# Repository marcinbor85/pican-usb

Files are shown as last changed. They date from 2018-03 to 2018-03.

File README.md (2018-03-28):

# pican-usb
Open-Hardware CAN-USB interface with optoisolation

## Features
- linux SOCKETCAN driver compatible (slcan)
- CANBUS side optoisolation (ISO1050 based)
- powered by USB (build-in DC/DC converter)
- hardware CAN and USB fifo buffers (8-deep CAN and 256-deep USB)
- virtual serial port (FT245 based)
- switchable build-in CAN terminal-resistor (symmetrical)
- up to 1Mbit throughput (no serial port bottleneck)
- EMC and ESD protection (both CAN and USB side)

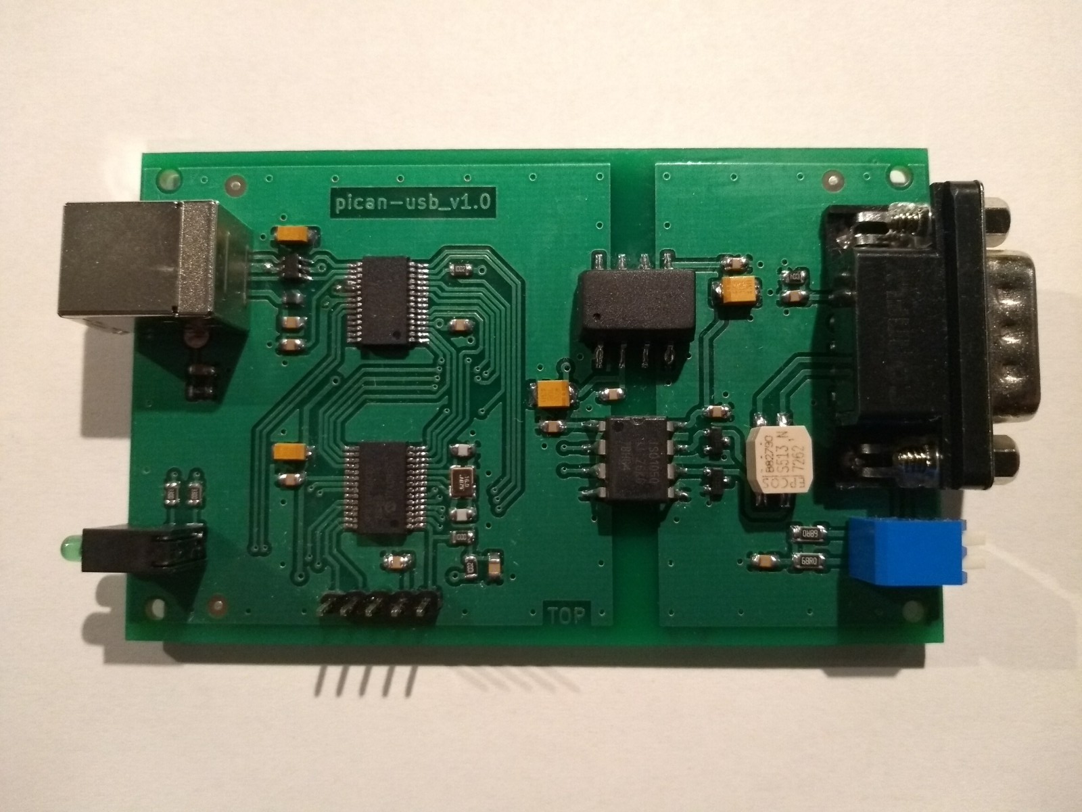
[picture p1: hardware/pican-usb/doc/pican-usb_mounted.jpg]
Board


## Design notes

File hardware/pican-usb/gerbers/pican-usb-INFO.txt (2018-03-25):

pican-usb_v1.0
--------------
laminat FR4 1.5mm 35um dwustronny
wymiary: 89.8mm x 55.3mm
metalizacja
soldermaska zielona
bez opisu elementów
cynowanie HAL
ilość otworów: 152
minimalny odstęp: 0.2mm
minimalna ścieżka: 0.4mm

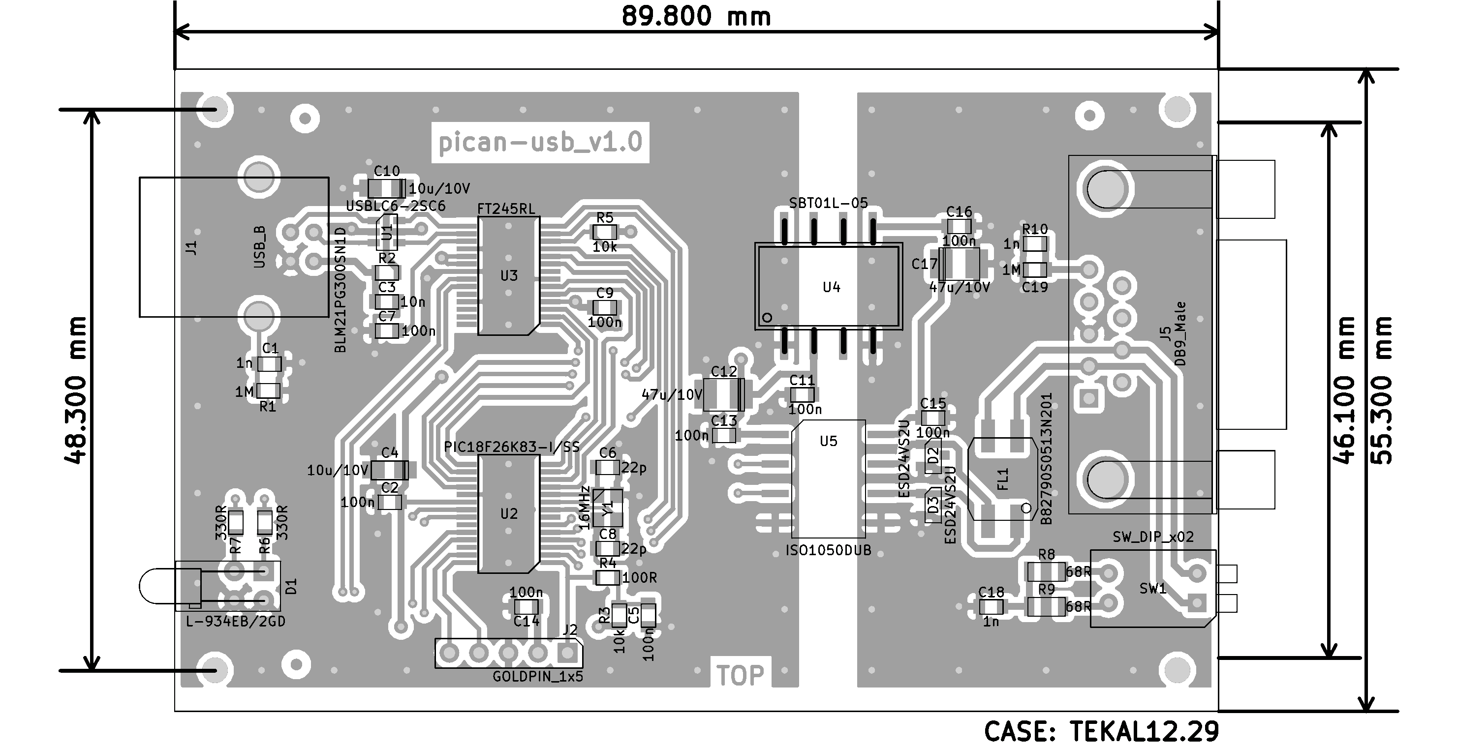
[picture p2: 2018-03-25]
hardware/pican-usb/doc/pican-usb.png

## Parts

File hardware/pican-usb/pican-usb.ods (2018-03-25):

Reference | Quantity | Identifier | Package | Value
U2 | 1 |  | Housings_SSOP:SSOP-28_5.3x10.2mm_Pitch0.65mm | PIC18F26K83-I/SS
J1 | 1 |  | mb_special:USB_B | USB_B
U3 | 1 |  | Housings_SSOP:SSOP-28_5.3x10.2mm_Pitch0.65mm | FT245RL
U5 | 1 |  | mb_special:ISO1050DUB | ISO1050DUB
FL1 | 1 |  | mb_special:B82790 | B82790S0513N201
R2 | 1 |  | Resistors_SMD:R_0805 | BLM21PG300SN1D
C6;C8 | 2 |  | Capacitors_SMD:C_0805 | 22p
C3 | 1 |  | Capacitors_SMD:C_0805 | 10n
C1;C18;C19 | 3 |  | Capacitors_SMD:C_0805 | 1n
R1;R10 | 2 |  | Resistors_SMD:R_0805 | 1M
R5;R3 | 2 |  | Resistors_SMD:R_0805 | 10k
D2;D3 | 2 |  | TO_SOT_Packages_SMD:SOT-23 | ESD24VS2U
C9;C13;C7;C2;C16;C15;C11;C14;C5 | 9 |  | Capacitors_SMD:C_0805 | 100n
C10;C4 | 2 |  | Capacitors_Tantalum_SMD:CP_Tantalum_Case-A_EIA-3216-18_Reflow | 10u/10V
U4 | 1 |  | mb_special:SBT01 | SBT01L-05
C17;C12 | 2 |  | Capacitors_Tantalum_SMD:CP_Tantalum_Case-B_EIA-3528-21_Reflow | 47u/10V
R4 | 1 |  | Resistors_SMD:R_0805 | 100R
D1 | 1 |  | mb_special:L-934EB2 | L-934EB/2GD
R6;R7 | 2 |  | Resistors_SMD:R_0805 | 330R
R8;R9 | 2 |  | Resistors_SMD:R_1206 | 68R
U1 | 1 |  | TO_SOT_Packages_SMD:SOT-23-6 | USBLC6-2SC6
J2 | 1 |  | Pin_Headers:Pin_Header_Straight_1x05_Pitch2.54mm | GOLDPIN_1x5
Y1 | 1 |  | Crystals:Crystal_SMD_3225-4pin_3.2x2.5mm | 16MHz
SW1 | 1 |  | Buttons_Switches_THT:SW_DIP_x2_W7.62mm_Piano | SW_DIP_x02
J5 | 1 |  | Connectors_DSub:DSUB-9_Male_Horizontal_Pitch2.77x2.84mm_EdgePinOffset7.70mm_Housed_MountingHolesOffset9.12mm | DB9_Male

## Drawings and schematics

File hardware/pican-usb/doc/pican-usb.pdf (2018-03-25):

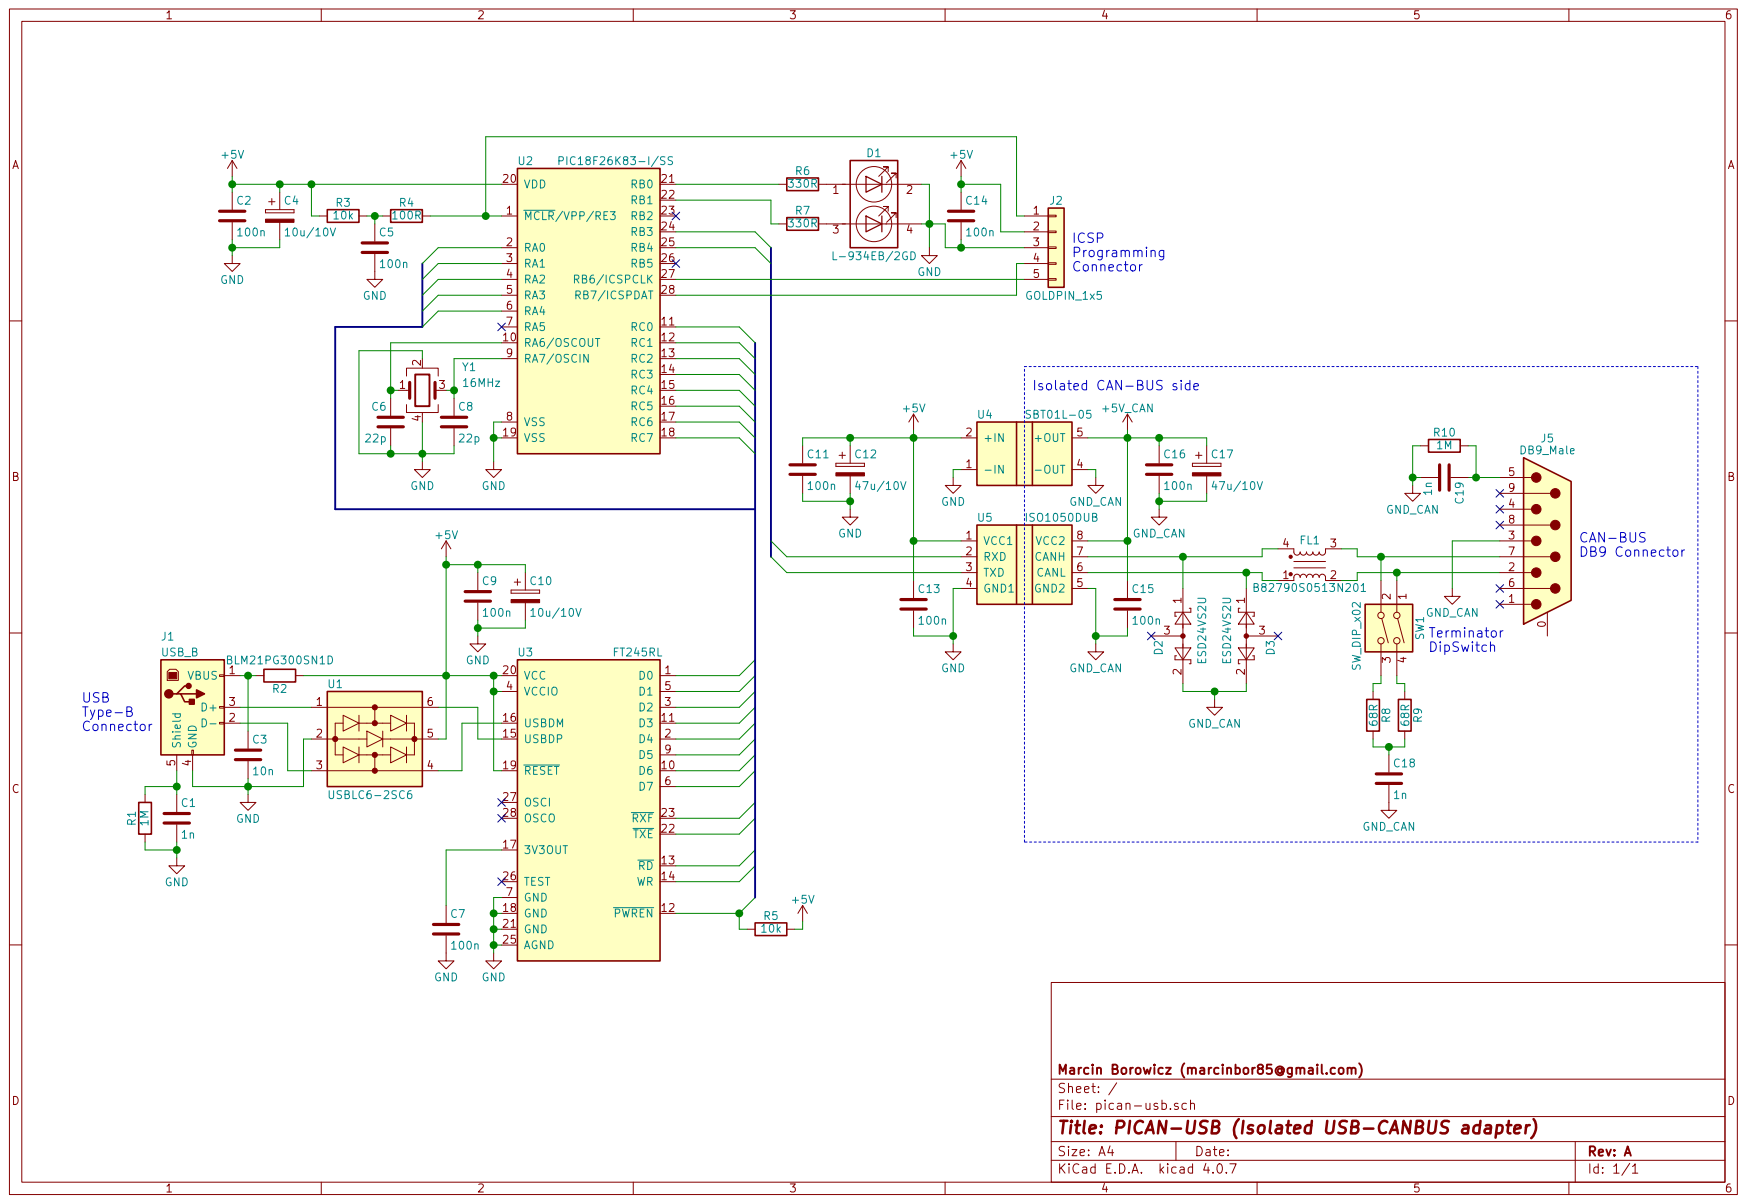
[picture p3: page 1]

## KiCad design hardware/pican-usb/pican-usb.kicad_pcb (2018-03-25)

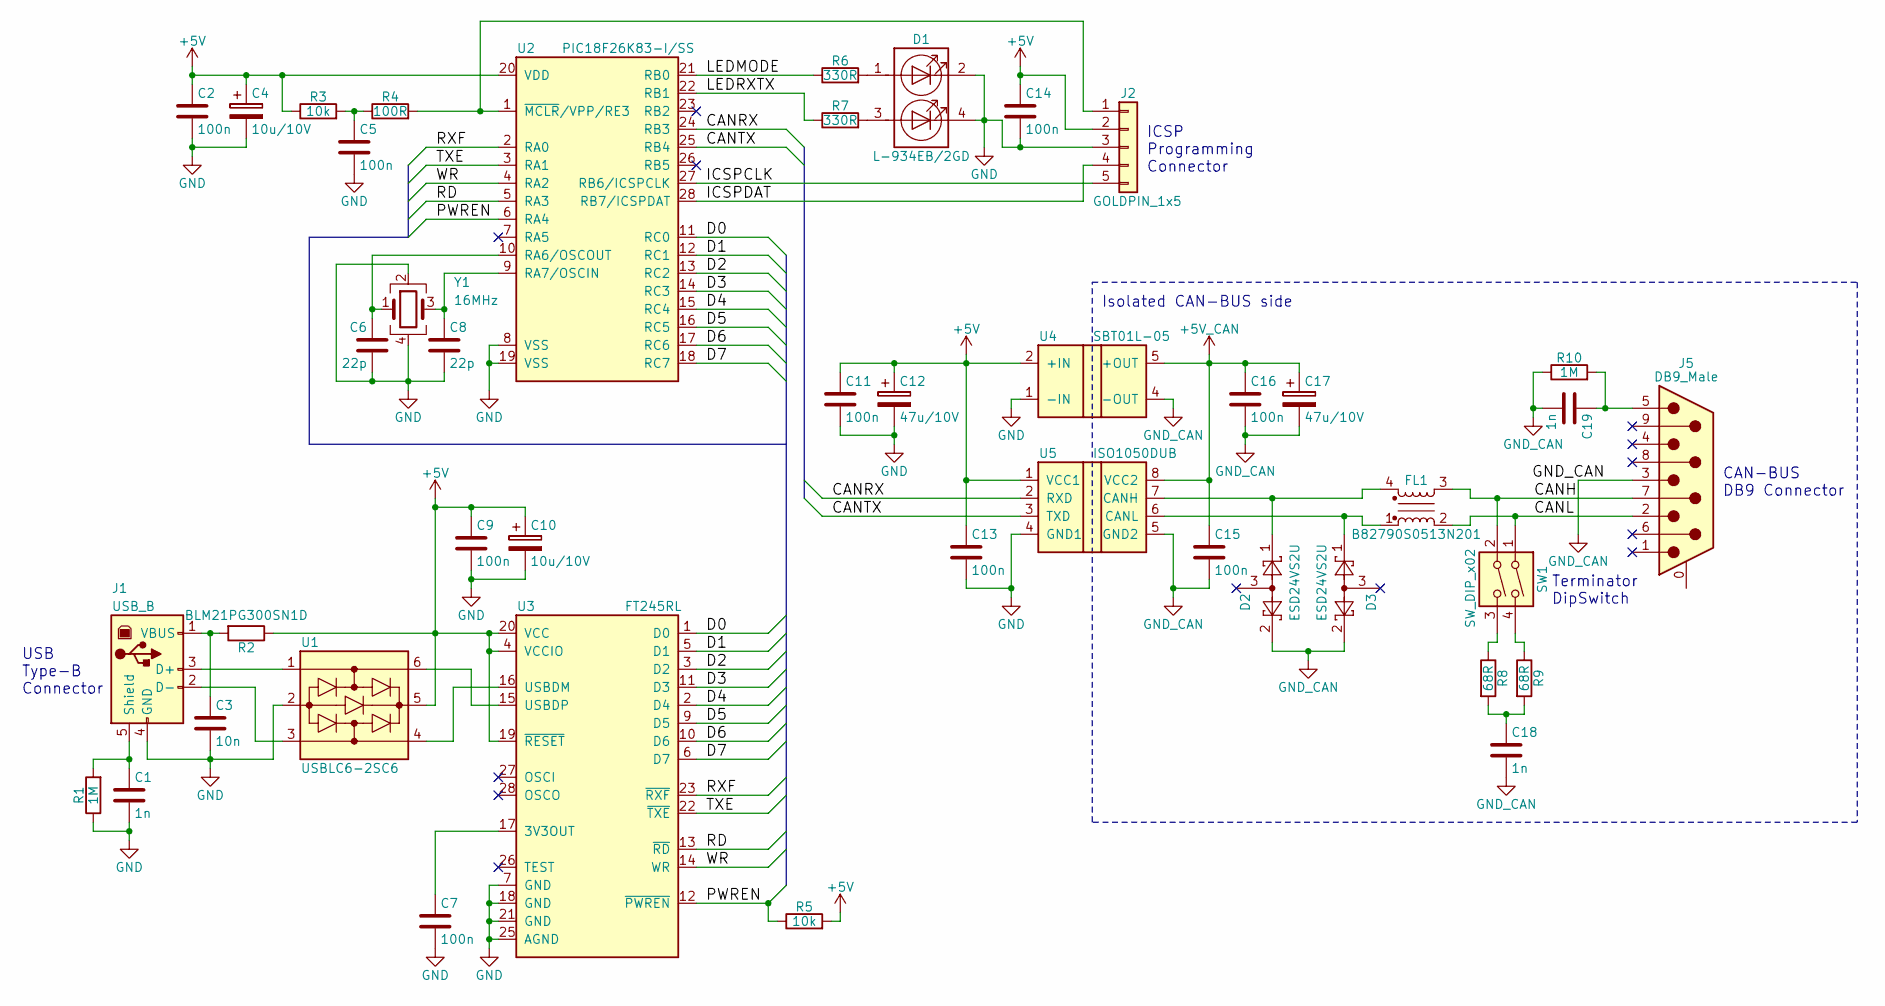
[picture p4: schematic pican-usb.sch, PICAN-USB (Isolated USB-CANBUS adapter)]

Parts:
C1, C18, C19: 1n; C_0805
C2, C5, C7, C9, C11, C13, C14, C15, C16: 100n; C_0805
C3: 10n; C_0805
C4, C10: 10u/10V; CP_Tantalum_Case-A_EIA-3216-18_Reflow
C6, C8: 22p; C_0805
C12, C17: 47u/10V; CP_Tantalum_Case-B_EIA-3528-21_Reflow
D1: L-934EB/2GD; L-934EB2
D2, D3: ESD24VS2U; SOT-23
FL1: B82790S0513N201; B82790
J1: USB_B
J2: GOLDPIN_1x5; Pin_Header_Straight_1x05_Pitch2.54mm
J5: DB9_Male; DSUB-9_Male_Horizontal_Pitch2.77x2.84mm_EdgePinOffset7.70mm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
R1, R10: 1M; R_0805
R2: BLM21PG300SN1D; R_0805
R3, R5: 10k; R_0805
R4: 100R; R_0805
R6, R7: 330R; R_0805
R8, R9: 68R; R_1206
SW1: SW_DIP_x02; SW_DIP_x2_W7.62mm_Piano
U1: USBLC6-2SC6; SOT-23-6
U2: PIC18F26K83-I/SS; SSOP-28_5.3x10.2mm_Pitch0.65mm
U3: FT245RL; SSOP-28_5.3x10.2mm_Pitch0.65mm
U4: SBT01L-05; SBT01
U5: ISO1050DUB
Y1: 16MHz; Crystal_SMD_3225-4pin_3.2x2.5mm

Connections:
+5V: C2.1, C4.1, C9.1, C10.1, C11.1, C12.1, C13.1, C14.1, J2.2, R2.1, R3.1, R5.2, U1.5, U2.20 (VDD), U3.4 (VCCIO), U3.19 (~RESET), U3.20 (VCC), U4.2 (+IN), U5.1 (VCC1)
+5V_CAN: C15.1, C16.1, C17.1, U4.5 (+OUT), U5.8 (VCC2)
/CANH: FL1.3, J5.7, SW1.2
/CANL: FL1.2, J5.2, SW1.1
/CANRX: U2.24 (RB3), U5.2 (RXD)
/CANTX: U2.25 (RB4), U5.3 (TXD)
/D0: U2.11 (RC0), U3.1 (D0)
/D1: U2.12 (RC1), U3.5 (D1)
/D2: U2.13 (RC2), U3.3 (D2)
/D3: U2.14 (RC3), U3.11 (D3)
/D4: U2.15 (RC4), U3.2 (D4)
/D5: U2.16 (RC5), U3.9 (D5)
/D6: U2.17 (RC6), U3.10 (D6)
/D7: U2.18 (RC7), U3.6 (D7)
/ICSPCLK: J2.5, U2.27 (RB6/ICSPCLK)
/ICSPDAT: J2.4, U2.28 (RB7/ICSPDAT)
/LEDMODE: R6.1, U2.21 (RB0)
/LEDRXTX: R7.1, U2.22 (RB1)
/PWREN: R5.1, U2.6 (RA4), U3.12 (~PWREN)
/RD: U2.5 (RA3), U3.13 (~RD)
/RXF: U2.2 (RA0), U3.23 (~RXF)
/TXE: U2.3 (RA1), U3.22 (~TXE)
/WR: U2.4 (RA2), U3.14 (WR)
GND: C1.2, C2.2, C3.2, C4.2, C5.2, C6.2, C7.2, C8.2, C9.2, C10.2, C11.2, C12.2, C13.2, C14.2, D1.2 (K1), D1.4 (K2), J1.4 (GND), J2.3, R1.1, U1.2, U2.8 (VSS), U2.19 (VSS), U3.7 (GND), U3.18 (GND), U3.21 (GND), U3.25 (AGND), U4.1 (-IN), U5.4 (GND1), Y1.2, Y1.4
GND_CAN: C15.2, C16.2, C17.2, C18.2, C19.2, D2.2, D3.2, J5.3, R10.1, U4.4 (-OUT), U5.5 (GND2)
unnamed: C1.1, J1.5 (Shield), R1.2
unnamed: C3.1, J1.1 (VBUS), R2.2
unnamed: C5.1, R3.2, R4.1
unnamed: C6.1, U2.10 (RA6/OSCOUT), Y1.1
unnamed: C7.1, U3.17 (3V3OUT)
unnamed: C8.1, U2.9 (RA7/OSCIN), Y1.3
unnamed: C18.1, R8.2, R9.2
unnamed: C19.1, J5.5, R10.2
unnamed: D1.1 (A1), R6.2
unnamed: D1.3 (A2), R7.2
unnamed: D2.1, FL1.4, U5.7 (CANH)
unnamed: D3.1, FL1.1, U5.6 (CANL)
unnamed: J1.2 (D-), U1.3
unnamed: J1.3 (D+), U1.1
unnamed: J2.1, R4.2, U2.1 (~MCLR~/VPP/RE3)
unnamed: R8.1, SW1.3
unnamed: R9.1, SW1.4
unnamed: U1.4, U3.16 (USBDM)
unnamed: U1.6, U3.15 (USBDP)

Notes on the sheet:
ICSP Programming Connector
CAN-BUS DB9 Connector
USB Type-B Connector
Terminator DipSwitch
Isolated CAN-BUS side

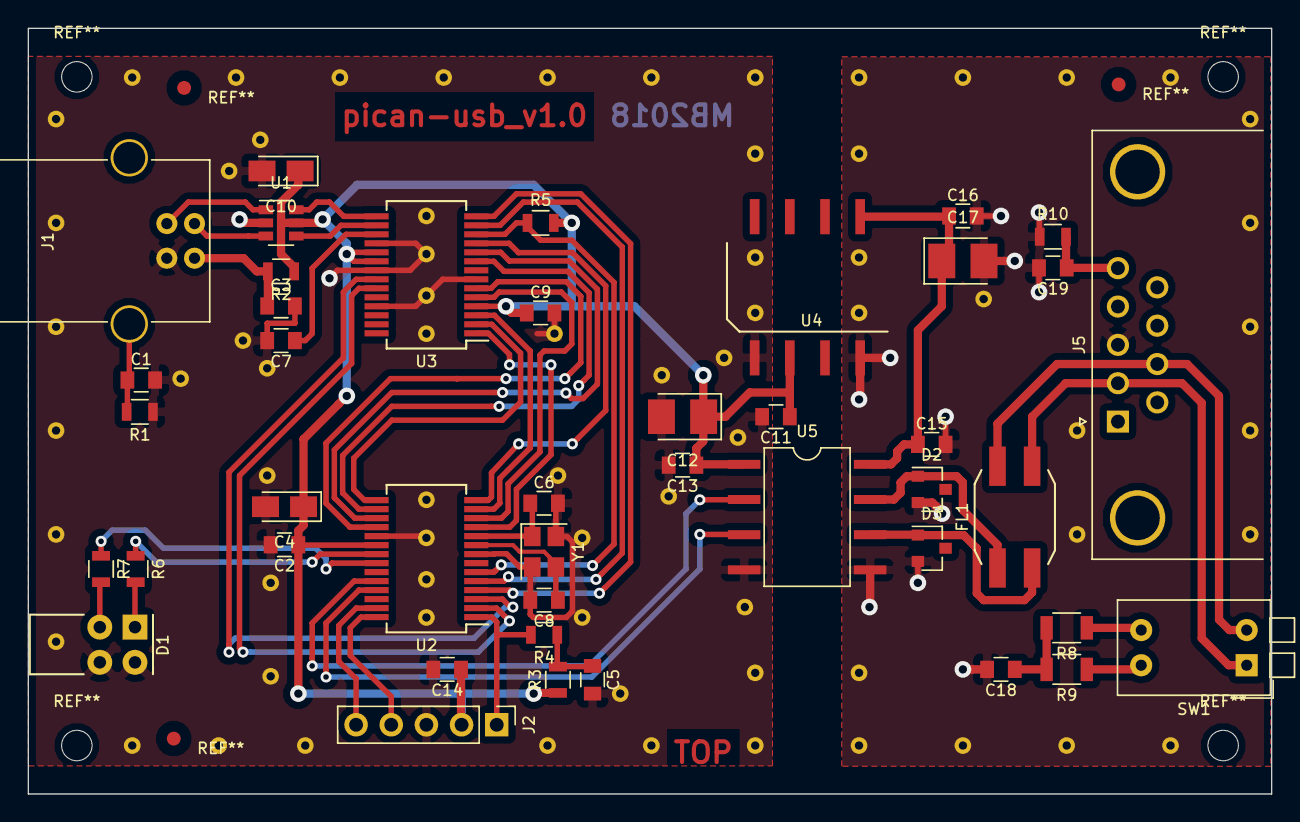
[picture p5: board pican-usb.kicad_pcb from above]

Board: 2 copper layers, 89.8 x 55.3 mm, 43 parts (0 on the bottom side), 44 nets.

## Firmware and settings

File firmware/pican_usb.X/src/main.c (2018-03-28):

#include "hw/hw.h"

#include <stdint.h>

#include "hal/tick.h"
#include "hal/leds.h"
#include "hal/can.h"

#include "hw/hw_ft245.h"

#include "net/ft245.h"
#include "net/slcan.h"

static uint8_t open_flag = 0;
static uint8_t std_ack_cntr = 0;
static uint8_t ext_ack_cntr = 0;
static uint8_t flash_flag = 0;
static uint8_t flash_state = 0;

static uint32_t last_tick = 0;
static uint32_t flash_tick = 0;

static struct slcan_object slcan;

static const uint8_t unique_serial[] = "FFFF";
static const uint8_t firmware_version[] = "0100";
static const uint8_t hardware_version[] = "0100";

static uint8_t recv_frame(struct can_frame *frame)
{
	if (open_flag == 0)
		return 1;
	if (can_send(frame) == 0)
		return 1;
	return 0;
}

static uint8_t open(uint32_t baudrate, uint8_t mode)
{
	if (open_flag != 0)
		return 1;
	
	switch (mode) {
	case SLCAN_MODE_NORMAL:
		can_init(baudrate, CAN_MODE_NORMAL);
		break;
	case SLCAN_MODE_LISTEN:
		can_init(baudrate, CAN_MODE_LISTEN);
		break;
	case SLCAN_MODE_LOOPBACK:
		can_init(baudrate, CAN_MODE_LOOPBACK);
		break;
	}
	open_flag = 1;
	return 0;
}

static uint8_t close(void)
{
	if (open_flag == 0)
		return 1;
	
	can_deinit();
	open_flag = 0;
	return 0;
}

static uint8_t get_status(void)
{
	return can_get_status();
}

static void send_byte(uint8_t b)
{
	while (ft245_put_byte(&ft245, b) == 0) {};
}

static struct slcan_interface slcan_iface = {
	recv_frame,
	open,
	close,
	get_status,
	send_byte,
	(uint8_t*)unique_serial,
	(uint8_t*)firmware_version,
	(uint8_t*)hardware_version
};

void can_send_callback(struct can_frame *frame)
{
	flash_flag = 1;
	slcan_tx_acknowledge(&slcan, frame);
}

static void clear_watchdog(void)
{
	CLRWDT();
}

static void leds_service(void)
{
	if (tick_get_value() - last_tick >= ((open_flag == 0) ? 500UL : 100UL)) {
		last_tick = tick_get_value();
		leds_toggle(LEDS_TYPE_OK);
	}

	switch (flash_state) {
	case 0:
		if (flash_flag == 1) {
			flash_flag = 0;
			flash_state = 1;
		}
		break;
	case 1:
		flash_tick = tick_get_value();
		leds_set(LEDS_TYPE_RXTX, 1);
		flash_state = 2;
		break;
	case 2:
		if (tick_get_value() - flash_tick >= 50UL) {
			flash_tick = tick_get_value();
			leds_set(LEDS_TYPE_RXTX, 0);
			flash_state = 3;
		}
		break;
	case 3:
		if (tick_get_value() - flash_tick >= 50UL) {
			if (flash_flag != 0) {
				flash_flag = 0;
				flash_state = 1;
			} else {
				leds_set(LEDS_TYPE_RXTX, 0);
				flash_state = 0;
			}
		}
		break;
	}
}

static void app_service(void)
{
	uint8_t b;
	struct can_frame frame;
	
	if (ft245_get_byte(&ft245, &b) != 0) {
		slcan_parse(&slcan, b);
	}

	if (open_flag != 0) {
		if (can_recv(&frame) != 0) {
			flash_flag = 1;
			slcan_send_frame(&slcan, &frame);
		}
		can_disable_tx_isr();
		slcan_tx_service(&slcan);
		can_enable_tx_isr();
	}
}

void main(void)
{	
	INTCON0bits.GIE = 0;
	CLRWDT();
	
	OSCCON1 = 0x20;
	while (OSCCON3bits.ORDY == 0) {};
	
	ANSELA = 0;
	ANSELB = 0;
	ANSELC = 0;
	
	tick_init();
	leds_init();
	
	ft245_init(&ft245);
	slcan_init(&slcan, &slcan_iface);

	INTCON0bits.GIE = 1;
	
	tick_delay(500, clear_watchdog);
	ft245_start();
	tick_delay(500, clear_watchdog);
	
	while (ft245_is_enumerated() == 0) {};

	leds_set(LEDS_TYPE_OK, 1);
	leds_set(LEDS_TYPE_RXTX, 0);
		
	while (1) {
		leds_service();
		app_service();
		
		if (ft245_is_enumerated() != 0)
			CLRWDT();
	}
}

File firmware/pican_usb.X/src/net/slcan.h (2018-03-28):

/* 
 * File:   slcan.h
 * Author: mborowicz
 *
 * Created on 24 marca 2018, 17:09
 */

#ifndef SLCAN_H
#define	SLCAN_H

#include <stdint.h>

#include "canbus.h"

#define SLCAN_MODE_NORMAL	0
#define SLCAN_MODE_LISTEN	1
#define SLCAN_MODE_LOOPBACK	2

#define SLCAN_BAUDRATE_0	10000UL
#define SLCAN_BAUDRATE_1	20000UL
#define SLCAN_BAUDRATE_2	50000UL
#define SLCAN_BAUDRATE_3	100000UL
#define SLCAN_BAUDRATE_4	125000UL
#define SLCAN_BAUDRATE_5	250000UL
#define SLCAN_BAUDRATE_6	500000UL
#define SLCAN_BAUDRATE_7	800000UL
#define SLCAN_BAUDRATE_8	1000000UL

#define SLCAN_BUFFER_SIZE	32

#define SLCAN_END_LINE_BYTE	0x0D
#define SLCAN_ERROR_BYTE	0x07

struct slcan_interface {
	uint8_t (*recv_frame)(struct can_frame *);
	uint8_t (*open)(uint32_t, uint8_t);
	uint8_t (*close)(void);
	uint8_t (*get_status)(void);
	void (*send_byte)(uint8_t);
	uint8_t *unique_serial;
	uint8_t *firmware_version;
	uint8_t *hardware_version;
};

struct slcan_object {
	const struct slcan_interface *iface;
	uint32_t baudrate;
	uint8_t buf[SLCAN_BUFFER_SIZE];
	uint8_t size;
	uint8_t std_tx_cntr;
	uint8_t ext_tx_cntr;
};

void slcan_init(struct slcan_object *slcan, const struct slcan_interface *iface);
void slcan_parse(struct slcan_object *slcan, uint8_t b);
void slcan_send_frame(struct slcan_object *slcan, struct can_frame *frame);
void slcan_tx_service(struct slcan_object *slcan);
void slcan_tx_acknowledge(struct slcan_object *slcan, struct can_frame *frame);

#endif	/* SLCAN_H */
